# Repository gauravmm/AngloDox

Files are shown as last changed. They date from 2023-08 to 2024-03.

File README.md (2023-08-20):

# AngloDox Keyboard

This is yet another split keyboard with the following features:

- Per-key RGB LEDs
- Separate function row
- RC-circuit debouncing for each key (the internal pullups allow you to swap switches while the keyboard is on!)
- Kailh hot-swap sockets
- USB-C connectors (but I2C protocol!) for the halves, with ESD protection
- Key polling via shift register instead of matrix
- Entirely manufacturable by JLCPCB, using basic parts as much as possible.

### Keyboard Layout

The keyboard layout is specified in `keyboard-layout.json` and can be edited in [KLE](http://www.keyboard-layout-editor.com/). The current layout is based on the reference ANSI-104 layout, with a macro column on the left, a collapsed arrow cluster on the right, and added thumb clusters from the venerable Ergodox keyboard.

The current layout has 46 keys on the left and 54 on the right, for a total of 100 keys.

## Development

This relies on a combination of scripts and hand-routing. Here's the general workflow:

    1. Generate the basic circuitry as a hierarchical schematic in KiCad.
    2. Specify a key layout as a [http://www.keyboard-layout-editor.com/#/](KLE) JSON file.
    3. Run the [KLE Placement Plugin](TODO) for the key layout.
    4. Specify the layout for each key next to the schematic for the key.
    5. Enforce the layout using the [HierarchicalPCB plugin](https://github.com/gauravmm/HierarchicalPcb).
    6. Route the parts between keys, using the swap positions option in the KLE Placement Plugin to improve performance.

### Regenerate KiCad Library

The Kicad library is generated using [JLC2KiCad_lib](https://github.com/TousstNicolas/JLC2KiCad_lib). To regenerate the library, run:

```bash
JLC2KiCadLib C1525 C25779 C36871 C965555 \
    -dir temp_jlc_import/
```

Then merge the symbol and footprint libraries into the main library manually. Remember to update the Value field of the symbols.

When setting up the Footprint library, set the nickname to `footprint`.

### Design Notes

Component selection is driven by what is available on JLCPCB as a basic part, making construction as cheap as possible. The only extended parts are the USB ESD protection circuit and the RJ11 connectors.

#### Crystal Design

We choose a [generic 12MHz oscillator](https://jlcpcb.com/partdetail/YangxingTech-X322512MSB4SI/C9002) as it is the cheapest basic part available on LCSC. As the load capacitance is 20pF, and the stray capacitance is assumed to be 5pF, we need a pair of 30pF capacitors to get the right frequency. (See [section 3.3 of the application note](https://www.st.com/resource/en/application_note/cd00221665-oscillator-design-guide-for-stm8af-al-s-stm32-mcus-and-mpus-stmicroelectronics.pdf) for the derivation.)

#### ESD Protection

For peace of mind, we add ESD protection to both USB-C ports.

1. Use a [generic bi-directional 6V TVS diode](https://jlcpcb.com/partdetail/Liown-SMF60CA/C2990473) between `VBUS` and `GND`.
2. Use a [USB-specific ESD protection circuit](https://jlcpcb.com/partdetail/Stmicroelectronics-USBLC62SC6/C7519) on the data lines. This is one of the few extended parts we use. This is based on the suggestions in [Phil's Lab tutorial](https://youtu.be/C7-8nUU6e3E?t=3842).
3. Short shield pins to GND directly. (This disagrees with the tutorial mentioned above.)

#### Half-to-half Connection

The halves are connected via USB-C to USB-C cables. This is preferable to TRRS cables (which have a nasty habit of shorting connections) and RJ11 cables (which are painfully tall and would have to be hand-soldered later). Since we're already paying the extended part fee for the connector, we might as well use them and enjoy the reversible connection it grants us.

To prevent damage from accidental connections, we apply the same ESD protections to the half-to-half connections as we do to the legitimate USB-C port.

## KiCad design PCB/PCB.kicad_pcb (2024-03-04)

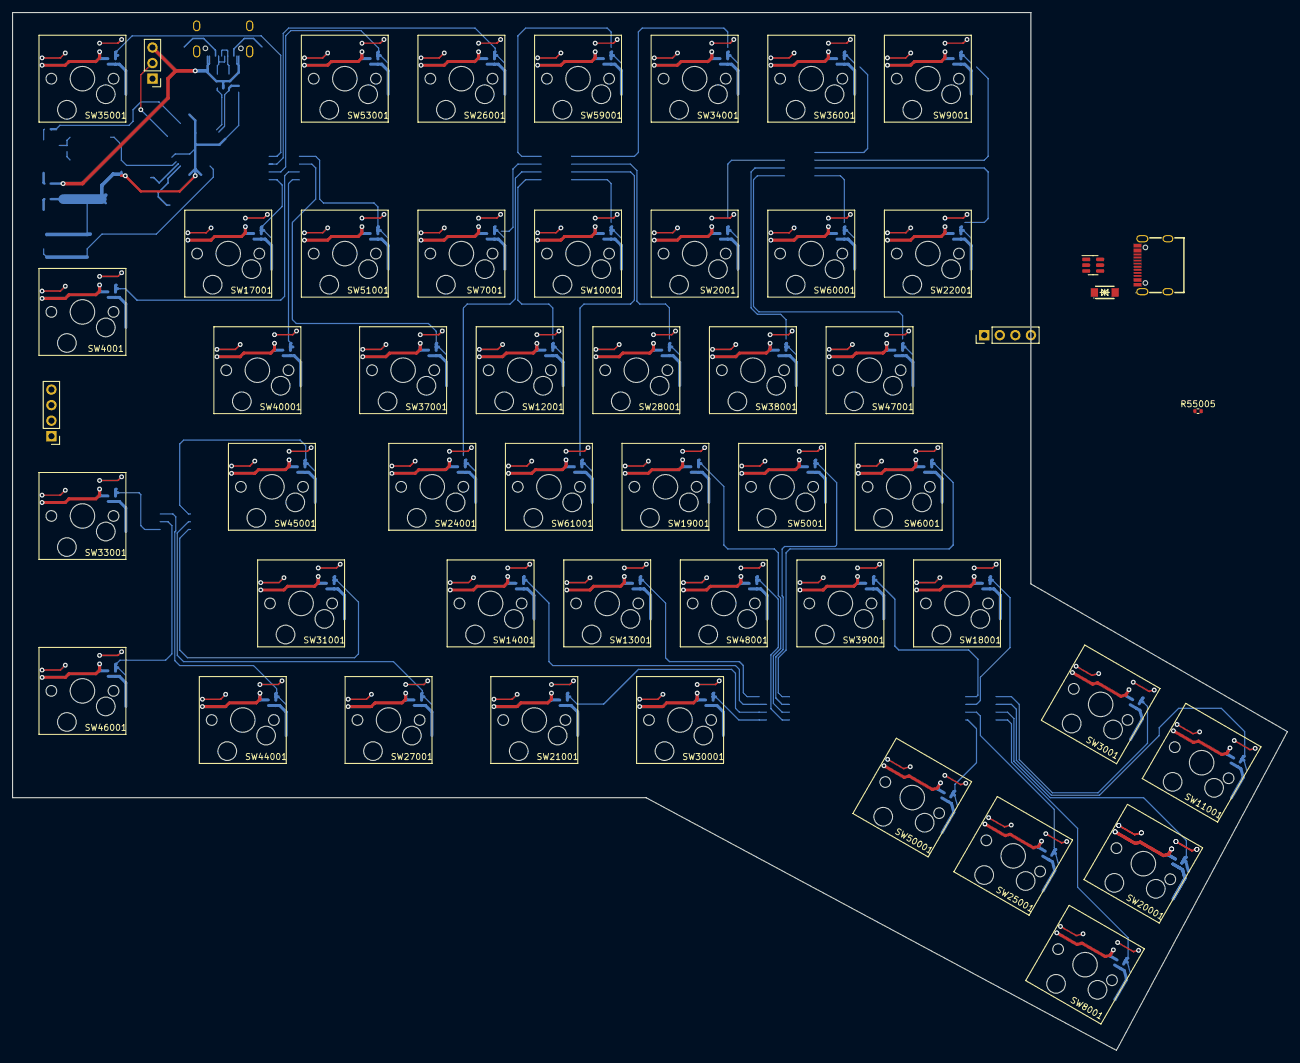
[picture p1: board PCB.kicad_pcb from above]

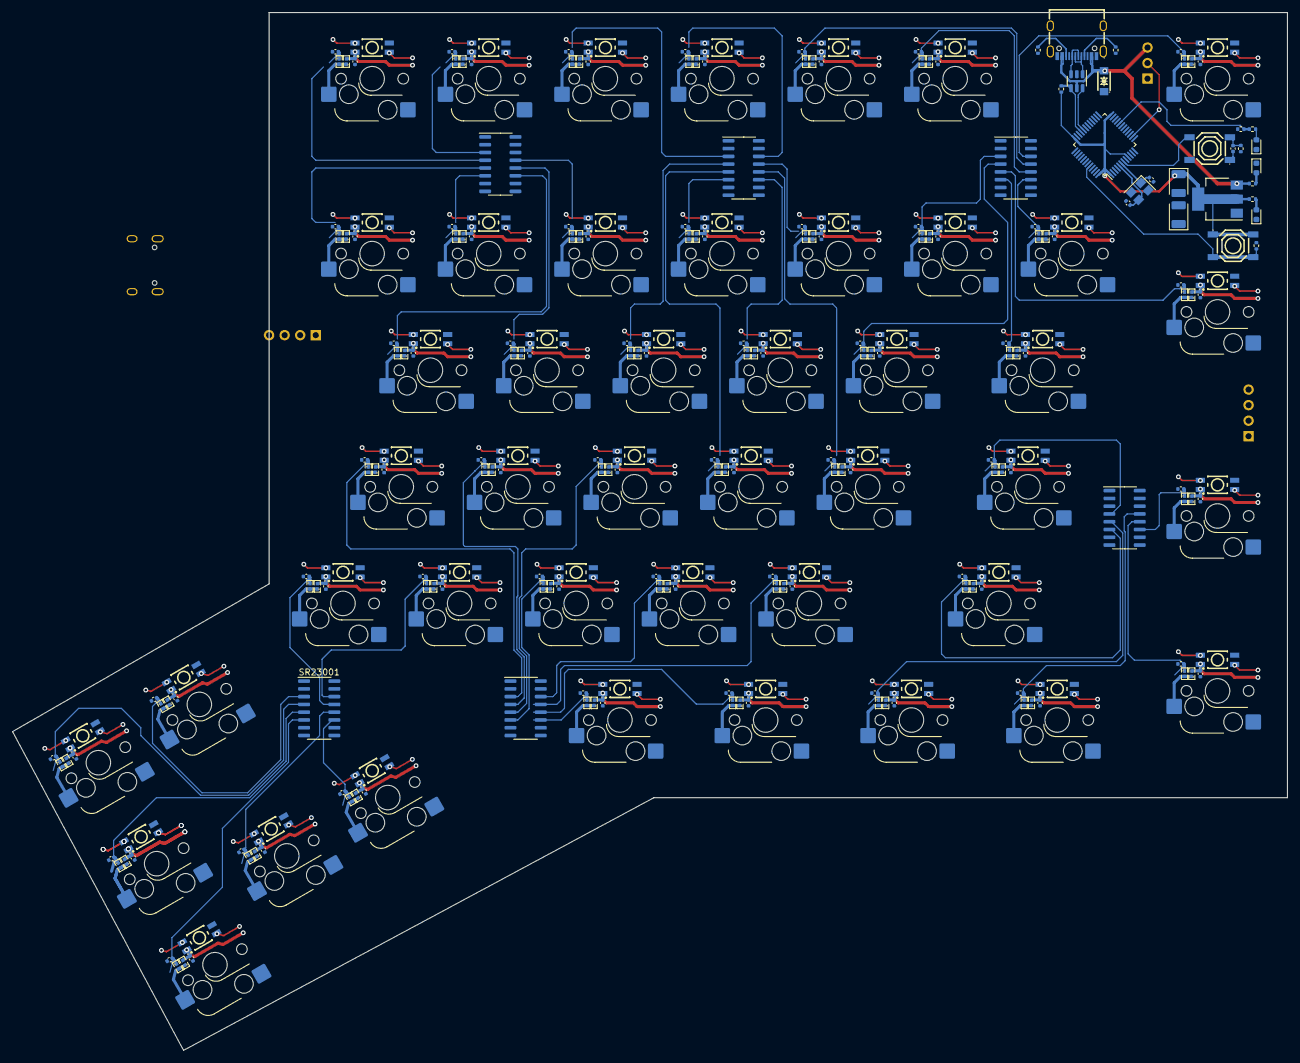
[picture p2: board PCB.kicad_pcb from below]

Board: 2 copper layers, 208.3 x 169.5 mm, 308 parts (256 on the bottom side), 129 nets.

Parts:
C55001, C55002: 30pF; C_0402_1005Metric
C55012: 100nF; C_0402_1005Metric
C55013, C55014: 100uF; CP_EIA-3528-15_AVX-H
CL2001, CL3001, CL4001, CL5001, CL6001, CL7001, CL8001, CL9001, CL10001, CL11001, CL12001, CL13001, CL14001, CL17001, CL18001, CL19001, CL20001, CL21001, CL22001, CL24001, CL25001, CL26001, CL27001, CL28001, CL30001, CL31001, CL33001, CL34001, CL35001, CL36001, CL37001, CL38001, CL39001, CL40001, CL44001, CL45001, CL46001, CL47001, CL48001, CL50001, CL51001, CL53001, CL59001, CL60001, CL61001: 100nF; C_0402_1005Metric
CS2001, CS3001, CS4001, CS5001, CS6001, CS7001, CS8001, CS9001, CS10001, CS11001, CS12001, CS13001, CS14001, CS17001, CS18001, CS19001, CS20001, CS21001, CS22001, CS24001, CS25001, CS26001, CS27001, CS28001, CS30001, CS31001, CS33001, CS34001, CS35001, CS36001, CS37001, CS38001, CS39001, CS40001, CS44001, CS45001, CS46001, CS47001, CS48001, CS50001, CS51001, CS53001, CS59001, CS60001, CS61001: 100nF; C_0402_1005Metric
D55001, D55003, D55004: Red; LED_0603_1608Metric
D55002, D60001: 6V ESD; SOD-123FL_L2.8-W1.8-LS3.7-BI
J55001: Debug; PinHeader_1x04_P2.54mm_Vertical
J60001: ALS; PinHeader_1x03_P2.54mm_Vertical
J60003: I2C; PinHeader_1x04_P2.54mm_Vertical
PB52001, PB55001: TS-1187A-B-A-B; SW-SMD_4P-L5.1-W5.1-P3.70-LS6.5-TL-2
R55001, R55003, R55004: 15k; R_0402_1005Metric
R55002, R55010: 1.5k; R_0402_1005Metric
R55005, R55006, R55007, R55008, R55009: 5.1k; R_0402_1005Metric
RA2001, RA3001, RA4001, RA5001, RA6001, RA7001, RA8001, RA9001, RA10001, RA11001, RA12001, RA13001, RA14001, RA17001, RA18001, RA19001, RA20001, RA21001, RA22001, RA24001, RA25001, RA26001, RA27001, RA28001, RA30001, RA31001, RA33001, RA34001, RA35001, RA36001, RA37001, RA38001, RA39001, RA40001, RA44001, RA45001, RA46001, RA47001, RA48001, RA50001, RA51001, RA53001, RA59001, RA60001, RA61001: 68kΩ; R0402
RB2001, RB3001, RB4001, RB5001, RB6001, RB7001, RB8001, RB9001, RB10001, RB11001, RB12001, RB13001, RB14001, RB17001, RB18001, RB19001, RB20001, RB21001, RB22001, RB24001, RB25001, RB26001, RB27001, RB28001, RB30001, RB31001, RB33001, RB34001, RB35001, RB36001, RB37001, RB38001, RB39001, RB40001, RB44001, RB45001, RB46001, RB47001, RB48001, RB50001, RB51001, RB53001, RB59001, RB60001, RB61001: 33kΩ; R0402
SR15001, SR16001, SR23001, SR32001, SR42001, SR54001: 74HC165; SOIC-16_3.9x9.9mm_P1.27mm
STM55001: STM32F103C8Tx; LQFP-48_7x7mm_P0.5mm
SW2001, SW3001, SW4001, SW5001, SW6001, SW7001, SW8001, SW9001, SW10001, SW11001, SW12001, SW13001, SW14001, SW17001, SW18001, SW19001, SW20001, SW21001, SW22001, SW24001, SW25001, SW26001, SW27001, SW28001, SW30001, SW31001, SW33001, SW34001, SW35001, SW36001, SW37001, SW38001, SW39001, SW40001, SW44001, SW45001, SW46001, SW47001, SW48001, SW50001, SW51001, SW53001, SW59001, SW60001, SW61001: SW_Push; SW_Hotswap_Kailh_MX
U2001, U3001, U4001, U5001, U6001, U7001, U8001, U9001, U10001, U11001, U12001, U13001, U14001, U17001, U18001, U19001, U20001, U21001, U22001, U24001, U25001, U26001, U27001, U28001, U30001, U31001, U33001, U34001, U35001, U36001, U37001, U38001, U39001, U40001, U44001, U45001, U46001, U47001, U48001, U50001, U51001, U53001, U59001, U60003, U61001: SK6812MINI-E_C5149201; LED-SMD_L3.2-W2.8-TR
U55001: AMS1117-3.3; SOT-223-3_TabPin2
U55002, U60001: TYPE-C-31-M-12; USB-C_SMD-TYPE-C-31-M-12
U55003, U60002: USBLC6-2SC6; SOT-23-6
X55001: Crystal; Crystal_SMD_3225-4Pin_3.2x2.5mm

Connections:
+3.3V: C55014.1, J55001.1, PB55001.1 (A), PB55001.2 (B), R55004.1, R55007.1, R55010.1, STM55001.1 (VBAT), STM55001.9 (VDDA), STM55001.24 (VDD), STM55001.36 (VDD), STM55001.48 (VDD), U55001.2 (VO)
+5V: C55013.1, CL2001.2, CL3001.2, CL4001.2, CL5001.2, CL6001.2, CL7001.2, CL8001.2, CL9001.2, CL10001.2, CL11001.2, CL12001.2, CL13001.2, CL14001.2, CL17001.2, CL18001.2, CL19001.2, CL20001.2, CL21001.2, CL22001.2, CL24001.2, CL25001.2, CL26001.2, CL27001.2, CL28001.2, CL30001.2, CL31001.2, CL33001.2, CL34001.2, CL35001.2, CL36001.2, CL37001.2, CL38001.2, CL39001.2, CL40001.2, CL44001.2, CL45001.2, CL46001.2, CL47001.2, CL48001.2, CL50001.2, CL51001.2, CL53001.2, CL59001.2, CL60001.2, CL61001.2, D55002.2, D60001.2, J60001.3, J60003.1, R55005.1, RA2001.2, RA3001.2, RA4001.2, RA5001.2, RA6001.2, RA7001.2, RA8001.2, RA9001.2, RA10001.2, RA11001.2, RA12001.2, RA13001.2, RA14001.2, RA17001.2, RA18001.2, RA19001.2, RA20001.2, RA21001.2, RA22001.2, RA24001.2, RA25001.2, RA26001.2, RA27001.2, RA28001.2, RA30001.2, RA31001.2, RA33001.2, RA34001.2, RA35001.2, RA36001.2, RA37001.2, RA38001.2, RA39001.2, RA40001.2, RA44001.2, RA45001.2, RA46001.2, RA47001.2, RA48001.2, RA50001.2, RA51001.2, RA53001.2, RA59001.2, RA60001.2, RA61001.2, SR15001.16 (VCC), SR16001.16 (VCC), SR23001.16 (VCC), SR32001.16 (VCC), SR42001.16 (VCC), SR54001.16 (VCC), U2001.1 (VDD), U3001.1 (VDD), U4001.1 (VDD), U5001.1 (VDD), U6001.1 (VDD), U7001.1 (VDD), U8001.1 (VDD), U9001.1 (VDD), U10001.1 (VDD), U11001.1 (VDD), U12001.1 (VDD), U13001.1 (VDD), U14001.1 (VDD), U17001.1 (VDD), U18001.1 (VDD), U19001.1 (VDD), U20001.1 (VDD), U21001.1 (VDD), U22001.1 (VDD), U24001.1 (VDD), U25001.1 (VDD), U26001.1 (VDD), U27001.1 (VDD), U28001.1 (VDD), U30001.1 (VDD), U31001.1 (VDD), U33001.1 (VDD), U34001.1 (VDD), U35001.1 (VDD), U36001.1 (VDD), U37001.1 (VDD), U38001.1 (VDD), U39001.1 (VDD), U40001.1 (VDD), U44001.1 (VDD), U45001.1 (VDD), U46001.1 (VDD), U47001.1 (VDD), U48001.1 (VDD), U50001.1 (VDD), U51001.1 (VDD), U53001.1 (VDD), U55001.3 (VI), U55002.A4 (VBUS), U55002.A9 (VBUS), U55002.B4 (VBUS), U55002.B9 (VBUS), U55003.5 (VBUS), U59001.1 (VDD), U60001.A4 (VBUS), U60001.A9 (VBUS), U60001.B4 (VBUS), U60001.B9 (VBUS), U60002.5 (VBUS), U60003.1 (VDD), U61001.1 (VDD)
/Left Half/8-Key Module1/SR_OUT: SR15001.10 (DS), SR42001.9 (Q7)
/Left Half/8-Key Module2/SR_OUT: SR15001.9 (Q7), SR16001.10 (DS)
/Left Half/8-Key Module3/SR_OUT: SR16001.9 (Q7), SR32001.10 (DS)
/Left Half/8-Key Module4/SR_OUT: SR23001.10 (DS), SR32001.9 (Q7)
/Left Half/8-Key Module5/SR_OUT: SR23001.9 (Q7), STM55001.38 (PA15)
/Left Half/8-Key Module/SR_CLOCK: SR15001.2 (CP), SR16001.2 (CP), SR23001.2 (CP), SR32001.2 (CP), SR42001.2 (CP), SR54001.2 (CP), STM55001.12 (PA2)
/Left Half/8-Key Module/SR_LOAD: SR15001.1 (~PL), SR16001.1 (~PL), SR23001.1 (~PL), SR32001.1 (~PL), SR42001.1 (~PL), SR54001.1 (~PL), STM55001.11 (PA1)
/Left Half/8-Key Module/SR_OUT: SR42001.10 (DS), SR54001.9 (Q7)
/Left Half/HALF_CONN_C: U60001.A5 (CC1), U60001.B5 (CC2)
/Left Half/HALF_CONN_N: U60001.A7 (DN1), U60001.B7 (DN2), U60002.1 (I/O1)
/Left Half/HALF_CONN_P: U60001.A6 (DP1), U60001.B6 (DP2), U60002.3 (I/O2)
/Left Half/HALF_CONN_S: U60001.A8 (SBU1), U60001.B8 (SBU2)
/Left Half/HALF_SCL: STM55001.42 (PB6), U60002.4 (I/O2)
/Left Half/HALF_SDA: STM55001.43 (PB7), U60002.6 (I/O1)
/Left Half/Key Unit0/SwitchOutput: CS9001.2, RB9001.1
/Left Half/Key Unit1/SwitchOutput: CS5001.2, RB5001.1, SR32001.4 (D5)
/Left Half/Key Unit2/SwitchOutput: CS8001.2, RB8001.1, SR23001.6 (D7)
/Left Half/Key Unit3/SwitchOutput: CS4001.2, RB4001.1, SR15001.5 (D6)
/Left Half/Key Unit4/SwitchOutput: CS7001.2, RB7001.1
/Left Half/Key Unit5/SwitchOutput: CS6001.2, RB6001.1, SR32001.3 (D4)
/Left Half/Key Unit6/SwitchOutput: CS2001.2, RB2001.1
/Left Half/Key Unit7/SwitchOutput: CS3001.2, RB3001.1, SR23001.3 (D4)
/Left Half/Key Unit11/SwitchOutput: CS18001.2, RB18001.1, SR23001.13 (D2)
/Left Half/Key Unit14/SwitchOutput: CS14001.2, RB14001.1, SR32001.13 (D2)
/Left Half/Key Unit15/SwitchOutput: CS17001.2, RB17001.1, SR15001.11 (D0)
/Left Half/Key Unit16/SwitchOutput: CS10001.2, RB10001.1
/Left Half/Key Unit17/SwitchOutput: CS19001.2, RB19001.1, SR32001.5 (D6)
/Left Half/Key Unit18/SwitchOutput: CS13001.2, RB13001.1, SR32001.14 (D3)
/Left Half/Key Unit19/SwitchOutput: CS12001.2, RB12001.1
/Left Half/Key Unit20/SwitchOutput: CS11001.2, RB11001.1, SR23001.4 (D5)
/Left Half/Key Unit21/SwitchOutput: CS26001.2, RB26001.1, SR15001.13 (D2)
/Left Half/Key Unit22/SwitchOutput: CS22001.2, RB22001.1
/Left Half/Key Unit23/SwitchOutput: CS21001.2, RB21001.1, SR32001.12 (D1)
/Left Half/Key Unit24/SwitchOutput: CS20001.2, RB20001.1, SR23001.5 (D6)
/Left Half/Key Unit25/SwitchOutput: CS24001.2, RB24001.1
/Left Half/Key Unit26/SwitchOutput: CS27001.2, RB27001.1, SR54001.5 (D6)
/Left Half/Key Unit27/SwitchOutput: CS25001.2, RB25001.1, SR23001.12 (D1)
/Left Half/Key Unit28/SwitchOutput: CS28001.2, RB28001.1
/Left Half/Key Unit29/SwitchOutput: CS36001.2, RB36001.1
/Left Half/Key Unit30/SwitchOutput: CS30001.2, RB30001.1, SR32001.11 (D0)
/Left Half/Key Unit31/SwitchOutput: CS35001.2, RB35001.1, SR15001.14 (D3)
/Left Half/Key Unit32/SwitchOutput: CS37001.2, RB37001.1, SR15001.4 (D5)
/Left Half/Key Unit33/SwitchOutput: CS33001.2, RB33001.1, SR54001.11 (D0)
/Left Half/Key Unit34/SwitchOutput: CS31001.2, RB31001.1, SR54001.6 (D7)
/Left Half/Key Unit35/SwitchOutput: CS34001.2, RB34001.1
/Left Half/Key Unit36/SwitchOutput: CS38001.2, RB38001.1
/Left Half/Key Unit37/SwitchOutput: CS39001.2, RB39001.1, SR23001.14 (D3)
/Left Half/Key Unit38/SwitchOutput: CS46001.2, RB46001.1, SR54001.12 (D1)
/Left Half/Key Unit39/SwitchOutput: CS47001.2, RB47001.1
/Left Half/Key Unit40/SwitchOutput: CS50001.2, RB50001.1, SR23001.11 (D0)
/Left Half/Key Unit41/SwitchOutput: CS48001.2, RB48001.1, SR32001.6 (D7)
/Left Half/Key Unit42/SwitchOutput: CS40001.2, RB40001.1, SR15001.6 (D7)
/Left Half/Key Unit43/SwitchOutput: CS44001.2, RB44001.1, SR54001.13 (D2)
/Left Half/Key Unit44/SwitchOutput: CS45001.2, RB45001.1, SR54001.4 (D5)
/Left Half/Key Unit45/SwitchOutput: CS53001.2, RB53001.1, SR15001.12 (D1)
/Left Half/Key Unit47/SwitchOutput: CS51001.2, RB51001.1, SR15001.3 (D4)
/Left Half/Key Unit49/SwitchOutput: CS60001.2, RB60001.1
/Left Half/Key Unit50/SwitchOutput: CS61001.2, RB61001.1
/Left Half/Key Unit51/SwitchOutput: CS59001.2, RB59001.1
/Left Half/STM32 Module/ADC12_IN4: J60001.2, STM55001.14 (PA4)
/Left Half/STM32 Module/BOOT0: PB55001.3 (C), PB55001.4 (D), R55003.1, STM55001.44 (BOOT0)
/Left Half/STM32 Module/BOOT1: R55001.1, R55002.1, STM55001.20 (PB2)
/Left Half/STM32 Module/I2C2_SCL: J60003.3, STM55001.21 (PB10)
/Left Half/STM32 Module/I2C2_SDA: J60003.2, STM55001.22 (PB11)
/Left Half/STM32 Module/NRST: PB52001.4 (D), STM55001.7 (NRST)
/Left Half/STM32 Module/USBDN: STM55001.32 (PA11), U55003.6 (I/O1)
/Left Half/STM32 Module/USBDP: R55010.2, STM55001.33 (PA12), U55003.4 (I/O2)
/Left Half/STM32 Module/USB_DN: U55002.A7 (DN1), U55002.B7 (DN2), U55003.1 (I/O1)
/Left Half/STM32 Module/USB_DP: U55002.A6 (DP1), U55002.B6 (DP2), U55003.3 (I/O2)
GND: C55001.1, C55002.1, C55013.2, C55014.2, CL2001.1, CL3001.1, CL4001.1, CL5001.1, CL6001.1, CL7001.1, CL8001.1, CL9001.1, CL10001.1, CL11001.1, CL12001.1, CL13001.1, CL14001.1, CL17001.1, CL18001.1, CL19001.1, CL20001.1, CL21001.1, CL22001.1, CL24001.1, CL25001.1, CL26001.1, CL27001.1, CL28001.1, CL30001.1, CL31001.1, CL33001.1, CL34001.1, CL35001.1, CL36001.1, CL37001.1, CL38001.1, CL39001.1, CL40001.1, CL44001.1, CL45001.1, CL46001.1, CL47001.1, CL48001.1, CL50001.1, CL51001.1, CL53001.1, CL59001.1, CL60001.1, CL61001.1, CS2001.1, CS3001.1, CS4001.1, CS5001.1, CS6001.1, CS7001.1, CS8001.1, CS9001.1, CS10001.1, CS11001.1, CS12001.1, CS13001.1, CS14001.1, CS17001.1, CS18001.1, CS19001.1, CS20001.1, CS21001.1, CS22001.1, CS24001.1, CS25001.1, CS26001.1, CS27001.1, CS28001.1, CS30001.1, CS31001.1, CS33001.1, CS34001.1, CS35001.1, CS36001.1, CS37001.1, CS38001.1, CS39001.1, CS40001.1, CS44001.1, CS45001.1, CS46001.1, CS47001.1, CS48001.1, CS50001.1, CS51001.1, CS53001.1, CS59001.1, CS60001.1, CS61001.1, D55001.1 (K), D55002.1, D55003.1 (K), D55004.1 (K), D60001.1, J55001.4, J60001.1, J60003.4, PB52001.2 (B), R55001.2, R55003.2, R55008.1, R55009.1, SR15001.8 (GND), SR16001.8 (GND), SR23001.8 (GND), SR32001.8 (GND), SR42001.8 (GND), SR54001.8 (GND), STM55001.8 (VSSA), STM55001.23 (VSS), STM55001.35 (VSS), STM55001.47 (VSS), SW2001.2, SW3001.2, SW4001.2, SW5001.2, SW6001.2, SW7001.2, SW8001.2, SW9001.2, SW10001.2, SW11001.2, SW12001.2, SW13001.2, SW14001.2, SW17001.2, SW18001.2, SW19001.2, SW20001.2, SW21001.2, SW22001.2, SW24001.2, SW25001.2, SW26001.2, SW27001.2, SW28001.2, SW30001.2, SW31001.2, SW33001.2, SW34001.2, SW35001.2, SW36001.2, SW37001.2, SW38001.2, SW39001.2, SW40001.2, SW44001.2, SW45001.2, SW46001.2, SW47001.2, SW48001.2, SW50001.2, SW51001.2, SW53001.2, SW59001.2, SW60001.2, SW61001.2, U2001.3 (GND), U3001.3 (GND), U4001.3 (GND), U5001.3 (GND), U6001.3 (GND), U7001.3 (GND), U8001.3 (GND), U9001.3 (GND), U10001.3 (GND), U11001.3 (GND), U12001.3 (GND), U13001.3 (GND), U14001.3 (GND), U17001.3 (GND), U18001.3 (GND), U19001.3 (GND), U20001.3 (GND), U21001.3 (GND), U22001.3 (GND), U24001.3 (GND), U25001.3 (GND), U26001.3 (GND), U27001.3 (GND), U28001.3 (GND), U30001.3 (GND), U31001.3 (GND), U33001.3 (GND), U34001.3 (GND), U35001.3 (GND), U36001.3 (GND), U37001.3 (GND), U38001.3 (GND), U39001.3 (GND), U40001.3 (GND), U44001.3 (GND), U45001.3 (GND), U46001.3 (GND), U47001.3 (GND), U48001.3 (GND), U50001.3 (GND), U51001.3 (GND), U53001.3 (GND), U55001.1 (GND), U55002.0 (SH), U55002.A1 (GND), U55002.A12 (GND), U55002.B1 (GND), U55002.B12 (GND), U55003.2 (GND), U59001.3 (GND), U60001.0 (SH), U60001.A1 (GND), U60001.A12 (GND), U60001.B1 (GND), U60001.B12 (GND), U60002.2 (GND), U60003.3 (GND), U61001.3 (GND), X55001.2, X55001.4
unnamed: D55001.2 (A), R55002.2
unnamed: D55003.2 (A), R55006.2
unnamed: D55004.2 (A), R55007.2
unnamed: J55001.2, STM55001.34 (PA13)
unnamed: J55001.3, STM55001.37 (PA14)
unnamed: C55012.1, PB52001.1 (A)
unnamed: C55012.2, PB52001.3 (C), R55004.2
unnamed: R55005.2, R55006.1
unnamed: RA2001.1, RB2001.2, SW2001.1
unnamed: RA3001.1, RB3001.2, SW3001.1
unnamed: RA4001.1, RB4001.2, SW4001.1
unnamed: RA5001.1, RB5001.2, SW5001.1
unnamed: RA6001.1, RB6001.2, SW6001.1
unnamed: RA7001.1, RB7001.2, SW7001.1
unnamed: RA8001.1, RB8001.2, SW8001.1
unnamed: RA9001.1, RB9001.2, SW9001.1
unnamed: RA10001.1, RB10001.2, SW10001.1
unnamed: RA11001.1, RB11001.2, SW11001.1
unnamed: RA12001.1, RB12001.2, SW12001.1
unnamed: RA13001.1, RB13001.2, SW13001.1
unnamed: RA14001.1, RB14001.2, SW14001.1
unnamed: RA17001.1, RB17001.2, SW17001.1
unnamed: RA18001.1, RB18001.2, SW18001.1
unnamed: RA19001.1, RB19001.2, SW19001.1
unnamed: RA20001.1, RB20001.2, SW20001.1
unnamed: RA21001.1, RB21001.2, SW21001.1
unnamed: RA22001.1, RB22001.2, SW22001.1
unnamed: RA24001.1, RB24001.2, SW24001.1
unnamed: RA25001.1, RB25001.2, SW25001.1
unnamed: RA26001.1, RB26001.2, SW26001.1
unnamed: RA27001.1, RB27001.2, SW27001.1
unnamed: RA28001.1, RB28001.2, SW28001.1
unnamed: RA30001.1, RB30001.2, SW30001.1
unnamed: RA31001.1, RB31001.2, SW31001.1
unnamed: RA33001.1, RB33001.2, SW33001.1
unnamed: RA34001.1, RB34001.2, SW34001.1
unnamed: RA35001.1, RB35001.2, SW35001.1
unnamed: RA36001.1, RB36001.2, SW36001.1
unnamed: RA37001.1, RB37001.2, SW37001.1
unnamed: RA38001.1, RB38001.2, SW38001.1
unnamed: RA39001.1, RB39001.2, SW39001.1
unnamed: RA40001.1, RB40001.2, SW40001.1
unnamed: RA44001.1, RB44001.2, SW44001.1
unnamed: RA45001.1, RB45001.2, SW45001.1
unnamed: RA46001.1, RB46001.2, SW46001.1
unnamed: RA47001.1, RB47001.2, SW47001.1
unnamed: RA48001.1, RB48001.2, SW48001.1
unnamed: RA50001.1, RB50001.2, SW50001.1
unnamed: RA51001.1, RB51001.2, SW51001.1
unnamed: RA53001.1, RB53001.2, SW53001.1
unnamed: RA59001.1, RB59001.2, SW59001.1
unnamed: RA60001.1, RB60001.2, SW60001.1
unnamed: RA61001.1, RB61001.2, SW61001.1
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

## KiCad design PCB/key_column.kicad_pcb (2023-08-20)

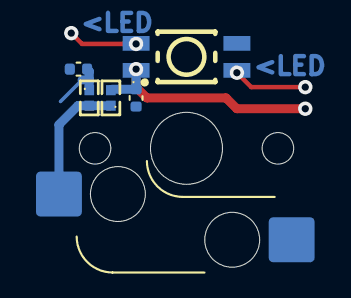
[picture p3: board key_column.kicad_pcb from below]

Board: 2 copper layers, 6 parts (5 on the bottom side), 4 nets.

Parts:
CL1201: 100nF; C_0402_1005Metric
CS1201: 100nF; C_0402_1005Metric
RA1201: 68kΩ; R0402
RB1201: 33kΩ; R0402
SW1201: SW_Push; SW_Hotswap_Kailh_MX
U1201: SK6812MINI-E_C5149201; LED-SMD_L3.2-W2.8-TR

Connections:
+5V: CL1201.2, RA1201.2, U1201.1 (VDD)
/SwitchOutput: CS1201.2, RB1201.1
GND: CL1201.1, CS1201.1, SW1201.2, U1201.3 (GND)
unnamed: RA1201.1, RB1201.2, SW1201.1

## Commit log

2023-07-26 PCB started.
    [PCB.kicad_pcb, PCB.kicad_sch, key_column.kicad_sch]
2023-07-27 Figured out the layout, now working on the PCB for each half.
    [PCB.kicad_pcb, PCB.kicad_sch, key_column.kicad_sch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]
2023-07-29 Working on STM32 circuit
    [PCB.kicad_sch, keeb_left.kicad_sch, key_column.kicad_sch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]
2023-07-29 Removed stm32, we're using a BluePill instead.
    [keeb_left.kicad_sch, key_module.kicad_sch, key_module_5.kicad_sch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]
2023-07-29 Done with STM32
    [keeb_left.kicad_sch, key_module.kicad_sch, key_module_5.kicad_sch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]
2023-07-29 Ready to work on PCB
    [PCB.kicad_pcb, keeb_left.kicad_sch, key_module.kicad_sch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]
2023-08-12 Plugin works.
    [PCB.kicad_pcb, keeb_left.kicad_sch, key_column.kicad_pcb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]
2023-08-20 Laying out the PCB.
    [PCB.kicad_pcb, keeb_left.kicad_sch, key_column.kicad_sch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]
2023-08-20 Removed 8-key units, now using the PCB view to handle routing the keys to the SOIP shift registers.
    [PCB.kicad_pcb, keeb_left.kicad_sch, key_column.kicad_pcb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]
2024-03-04 Updated schematics for KiCAD 8
    [PCB.kicad_pcb, PCB.kicad_sch, keeb_left.kicad_sch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]
